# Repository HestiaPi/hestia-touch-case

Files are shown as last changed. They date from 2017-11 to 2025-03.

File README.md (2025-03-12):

# HestiaPi Touch

HestiaPi Touch

HestiaPi Touch is a completely open source smart thermostat for your home. With it, you can monitor your home’s temperature, relative humidity, and atmospheric pressure. You can also control your heating, ventilation, air conditioning, hot water, and more from anywhere you have an Internet connection. 

You can do all this securely and with confidence your private data stays private. 

HestiaPi Touch is compatible with many devices and home automation systems and can serve as a central point of control that ties them all together in your home.

# What are all these files?

TL;DR: Download Backplate_ONE.stl and the Cover_ONE stl which matches the power supply you have, adjust printer/filament settings, and print.

## File types

- FCStd: FreeCAD models of the case
- stl: Exported models in a standard format (STL)

## The printing process
Open a slicer like Cura or Prussa, open the STL and set all your print settings (temperature, infill, supports, and so forth).

After that you'll either press Print via USB or save the .gcode to an SD card and put it in your printer to print in standalone mode. If this is your first time printing something, I'd advise having someone experienced in 3D printing to help you along the process.

## Different editions
The US power supply (24V) is larger than the EU one and so the LCD screen rests directly on the power supply. As such, one of the LCD tabs had to be removed in order to avoid it from colliding with the airspace of the power supply.

The EU power supply (240V) is smaller and requires that third tab be there in order to keep the LCD in place.

# Update process
The process to update these models is to use FreeCAD to modify the model and make sure to update the version number. When done, export to STL. Commit all of these files to the git repo with an explanation of what changed in the commit message. Submit a merge request.

As long as the modified design will still fit with the other piece (e.g. your modified cover still fits the current backplate), the version number should go up by 0.01. If you are introducing an incompatibility, the version number should go up by 0.1. The only time the version number would change more than this if if it is a radical redesign.

# Compatibility
The current models (made in FreeCAD) are not a perfect match with the old ones (made in Onshape). The Onshape models never had a version number. The FreeCAD models got version numbers in 2025. Version numbers are engraved on the inside of the cover and the back of the backplate.

Anything with a version number where the first two digits match will be compatible. For example, the EU Cover v2.1 is compatible with the Backplate v2.11.

If you need a replacement and are not sure which model you have, the safest thing to do is to print a new backplate and cover with a known version number. Of course, you can also print out just the piece that you need and just see if it fits.

# Useful links

* [Main website](https://hestiapi.com/)
* [Documentation & Getting Started Guides](https://github.com/HestiaPi/hestia-touch-openhab/wiki)
* [Community forum](https://community.hestiapi.com/)
* [Code](https://github.com/HestiaPi/hestia-touch-openhab)
* [Electronics](https://github.com/HestiaPi/hestia-touch-pcb-dev)
* [3D Case (this repo)](https://github.com/HestiaPi/hestia-touch-case)

# Support us

HestiaPi is and will always be open source and open hardware. 

Please consider supporting us through our [crowdfunding campaign](https://www.crowdsupply.com/makeopenstuff/hestiapi-touch).

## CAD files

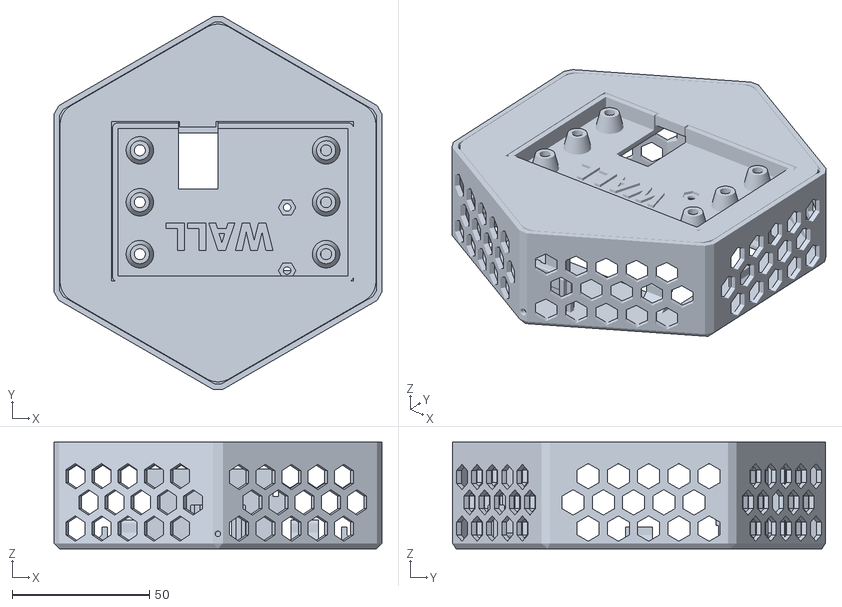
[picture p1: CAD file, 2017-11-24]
HestiaPi Touch Hex Assembly.stl
119.3 x 135.8 x 38.8

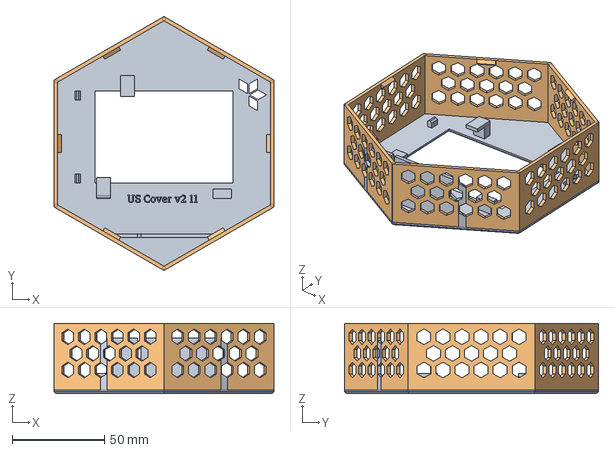
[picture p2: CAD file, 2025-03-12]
Cover_ONE_US_24V.FCStd
119.3 x 137.8 x 38.0 mm
Front plate
Side

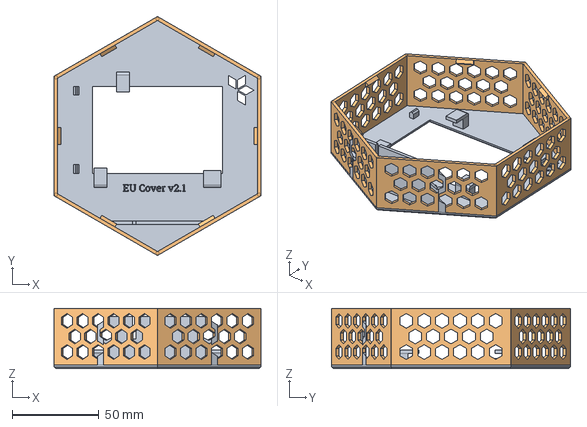
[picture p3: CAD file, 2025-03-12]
Cover_ONE_EU_240V.FCStd
119.3 x 137.8 x 34.8 mm
Front plate
Side

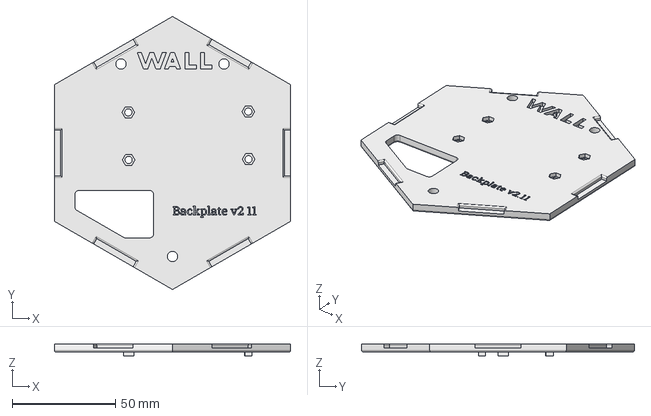
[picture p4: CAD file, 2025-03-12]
Backplate_ONE.FCStd
114.3 x 132.0 x 6.00 mm

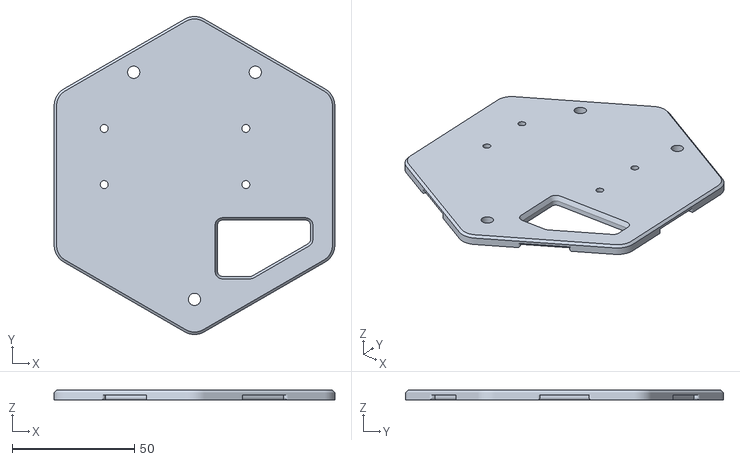
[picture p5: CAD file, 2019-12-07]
BaseONESnap2HNuts.stl
114.9 x 130.2 x 4.00

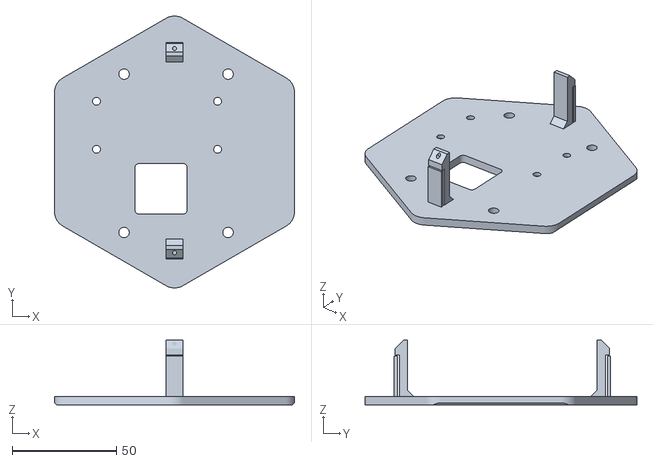
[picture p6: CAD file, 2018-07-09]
HestiaPi Touch Hex Plate v3.stl
114.9 x 130.2 x 31.0

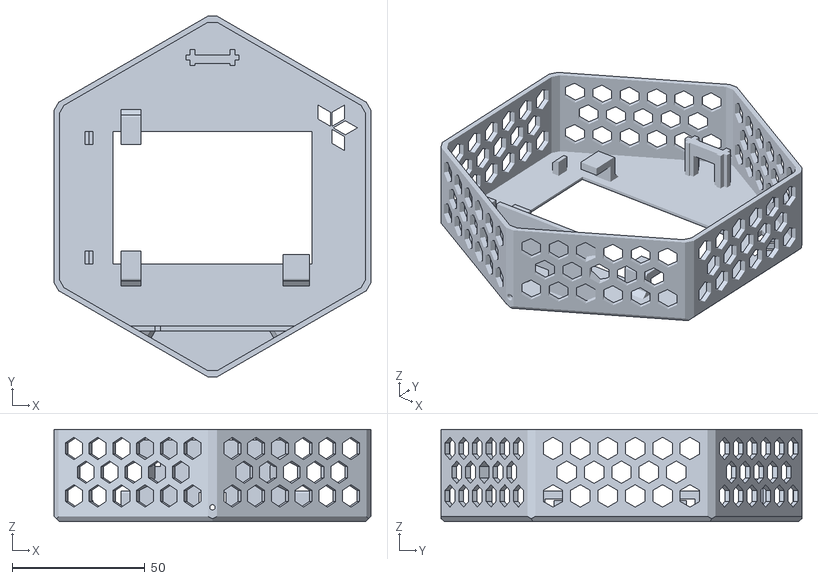
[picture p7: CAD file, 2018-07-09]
HestiaPi Touch Hex Cover v3.stl
119.3 x 135.8 x 34.8

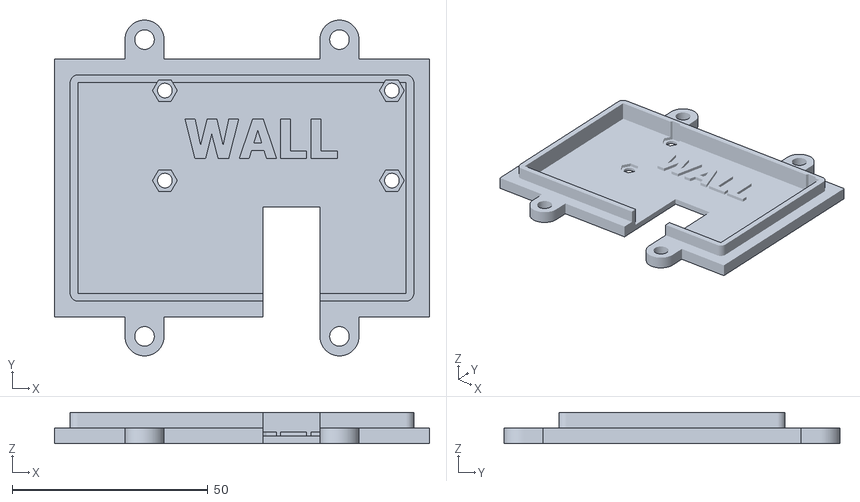
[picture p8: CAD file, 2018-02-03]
HestiaPi Touch Hex Base v2.stl
95.8 x 85.8 x 8.00

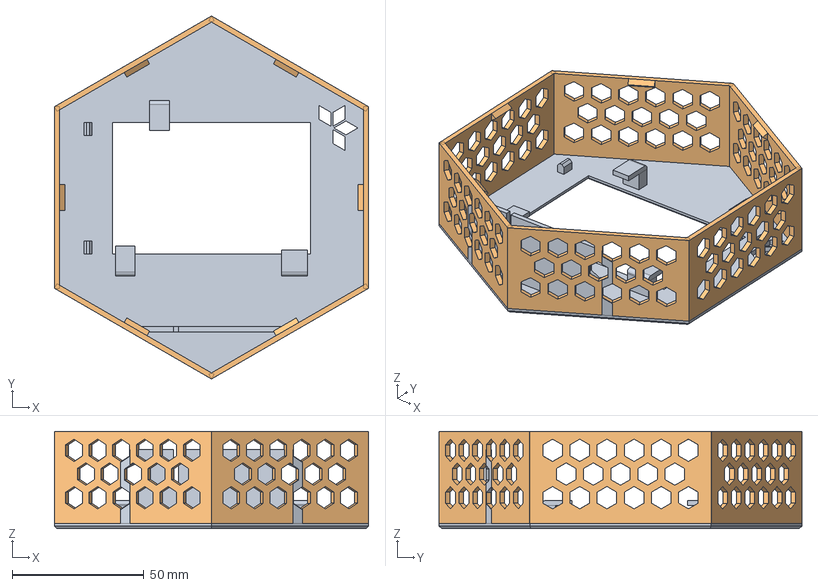
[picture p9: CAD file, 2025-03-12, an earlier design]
archive/CoverOneSnap2H_v2.1-35mm.FCStd
119.3 x 137.8 x 37.0 mm
Front plate
Side

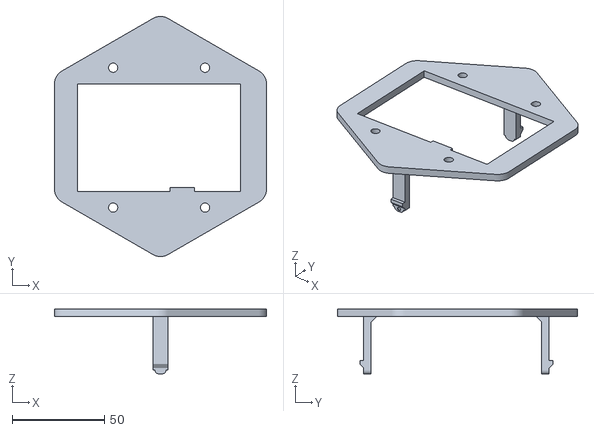
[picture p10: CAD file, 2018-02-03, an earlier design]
archive/HestiaPi Touch Hex Plate v2.stl
114.9 x 130.2 x 35.0

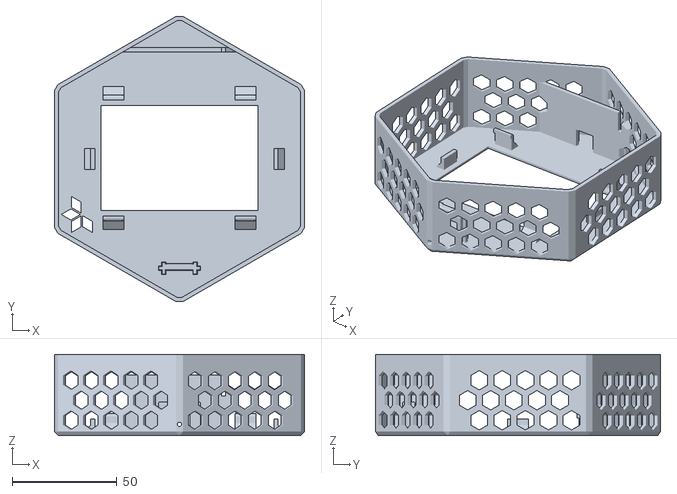
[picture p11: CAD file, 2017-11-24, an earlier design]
archive/HestiaPi Touch Hex Cover v2.stl
119.3 x 135.8 x 38.8

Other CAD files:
archive/CoverOneSnap2H_v2.1-Clicky-US-24V.FCStd
Backplate_ONE.stl
Cover_ONE_EU_240V.stl
Cover_ONE_US_24V.stl
archive/CoverOneSnap2H_v2.1-35mm.stl
archive/CoverOneSnap2H_v2.1-Clicky-US-24V.stl

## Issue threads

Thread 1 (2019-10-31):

LCD's screen appears off-center when mounted

jaythomas, 2019-10-31:
There is a blank portion of the LCD on the right side that makes it look off-center.

Sorry for the blurry pic:

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

This is an after-stock screen, but the issue appears on the original screen as well. Perhaps the back mounts can be adjusted to better align everything.

gulliverrr, 2019-10-31:
I am pretty sure you are viewing the full LCD.
The actual LCD is not indeed "centered" and there is a gap on the right:
https://www.waveshare.com/w/upload/2/22/3.5inch-RPi-LCD-B-Manual-20.png
but the mounts are actually located and aligned with the frame to center it. Have you pushed the LCD all the way to touch the side mounts?
Measure the visible width with a ruler if it is 73.44mm, that is 2.89 in inches, taken from the above link.

jaythomas, 2019-10-31:
It's flush with the side mounts. Since the pi and thermostat board are mounted to the wall and backplate there isn't much wiggle room to adjust the screen unfortunately. I'll cross check the dimensions to the waveshare model and see what I can do, thanks.

Closed 2019-10-31.

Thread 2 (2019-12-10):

Bottom wall screw

gulliverrr, 2019-12-10:
Screw's head may block the cover to fully insert. Move the hole or make clearance on the partition.

hestiahacker, 2023-09-07:
Is this in reference to the bottom screw that goes through the back plate?

It looks like the divider is about 17mm from the bottom corner and the center of that hole is about 14mm from that same corner.

Assuming I understand the issue correctly, would moving that hole down by 3mm address this issue?

gulliverrr, 2023-10-31:
This is a leftover since the case was a 3-piece assembly. Please ignore. Closing...

Closed 2023-10-31.

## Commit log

2017-04-01 Added 'WALL' marking
    [HestiaPi Touch Base.stl]
2017-04-01 Designer proposal
    This is not a printable design!
    [HestiaPi Touch Hex Case.stl]
2017-10-03 Semi final main case
    Missing correct hinges that lock the LCD position.
    Missing hole for securely fixing front case to back plate.
    [HestiaPi Touch Hex Case.stl]
2017-11-24 First Official Release of the Hex Case
    [HestiaPi Touch Hex Assembly.stl, HestiaPi Touch Hex Base.stl, HestiaPi Touch Hex Cover.stl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]
2017-11-24 Official Release uses different naming
    [HestiaPi Touch Hex Case.stl]
2018-02-03 Version 2 fixes some alignment issues
    [HestiaPi Touch Hex Base v2.stl, HestiaPi Touch Hex Cover v2.stl, HestiaPi Touch Hex Plate v2.stl]
2018-07-09 New 2-part design
    The latest part has only two parts and holds the LCD much better with a twist and lock method.
    [HestiaPi Touch Hex Cover v3.stl, HestiaPi Touch Hex Plate v3.stl]
2019-12-09 Simplify filename
    [CoverOneSnap2H-24+220.stl]
2023-07-06 feat: modified original CAD model to be taller
    This means it protrudes further from the wall. This is to allow for larger
    tolerances. The issues this expects to solve are:
    - Case won't close because LCD tabs hit the 24V -> 5V converter
    - LCD won't work because screen is pinched against the case
    - Case won't close because there's not enough clearance for the LCD pins
    [CoverOneSnap2H-taller.stl]
2023-07-06 feat: Remodeled case in FreeCAD
    The previous model was done in OnShape, which is a propritary web-based
    platform. It is easy to use, and they give out free accounts for personal
    use, however the free accounts could be discontinued at any time, leaving
    us with only the .stl files. If that happened, making changes to the model
    would be very difficult. By recreating the model in FreeCAD, we don't have to
    worry about this.
    In addition, this makes the case 4mm taller (protruding from the wall further)
    in order to solve some issues we've seen, such as:
    - Touchscreen not working because the case is too short for the LCD pins
    - Case won't close because the LCD tab collides with the AC/DC converter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
    [CoverOneSnap2H_v2.1.FCStd, CoverOneSnap2H_v2.1.stl]
2023-07-07 feat: use spreadsheet values to control case properties
    There is now a spreadsheet which will control the interior height of the case
    and the LCD screen's thickness that the tabs need to fit.
    [CoverOneSnap2H_v2.1.FCStd]
2023-07-08 fix: added retention tabs to top of the side walls
    [CoverOneSnap2H_v2.1.FCStd]
2023-09-07 fix: final touches to adjust tolerances in the FreeCAD case
    [BaseOneSnap2HNuts_v2.1.FCStd, BaseOneSnap2HNuts_v2.1.stl, CoverOneSnap2H_v2.1.FCStd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]
2023-11-08 maint: set side height back to 32.8mm because we're switching away from the problematic pins
    [CoverOneSnap2H_v2.1.FCStd]
2023-11-19 Improved documentation and perfected the 35mm edition
    The standard case works well for the silent version of the HestiaPi ONE
    as long as the correct length LCD headers can be obtained.
    However, the clicky edition of the HestiaPi ONE has the temperature
    sensor on the back of the board, which makes the board sit higher. This
    causes the case to be just a couple millimeters too short. to fit
    everything into the case. The 35mm edition of the cover was created to
    address this problem.
    Also updated the README to help people navigate this repo and added the
    height of the original case into the spreadsheet in the FreeCAD model
    so people can easily tell if the height has been modified.
    [BaseOneSnap2H_v2.1_M2-SE.3mf, CoverOneSnap2H_v2.1-35mm.FCStd, CoverOneSnap2H_v2.1-35mm.stl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]
2023-12-15 Tightened tolerance with shell and moved pi mounting holes slightly to better accomidate the clicky edition
    [BaseOneSnap2HNuts_v2.1.FCStd, BaseOneSnap2HNuts_v2.1.stl]
2023-12-17 Adjusted the retaining clips on the case to be easier attach or detach the cover
    [CoverOneSnap2H_v2.1-35mm.FCStd, CoverOneSnap2H_v2.1-35mm.stl, CoverOneSnap2H_v2.1-Clicky-US-24V.FCStd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]
2023-12-18 Added stand-offs to the base so the PCB sits level and exactly 3mm above the base
    [BaseOneSnap2HNuts_v2.1.FCStd, BaseOneSnap2HNuts_v2.1.stl]
2023-12-18 Removed 3mf files to avoid them getting out of sync; they can be generated from the .stl files
    [BaseOneSnap2H_v2.1_M2-SE.3mf, CoverOneSnap2H_v2.1-35mm_M2-SE.3mf, CoverOneSnap2H_v2.1_M2-SE.3mf]
2024-07-23 Made shell 1 mm taller and use the modified LCD tabs to make room for the 24V power adapter
    [CoverOneSnap2H_v2.2-US-24V.FCStd, CoverOneSnap2H_v2.2-US-24V.stl]
2025-02-28 maint: Organized files so it's easier to use & some tweaks
    - Reorganized files and updated README accordingly
    - Allows people to find the files that are appropriate for them
    - Lowered standoffs on the backplate to improve tolerances
    - Added version numbers into the actual CAD model
    - Allows people to know what model they have
    This should make maintaining these case models much more managable
    [Backplate_ONE.FCStd, Backplate_ONE.stl, BaseONESnap2HNuts.stl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]
